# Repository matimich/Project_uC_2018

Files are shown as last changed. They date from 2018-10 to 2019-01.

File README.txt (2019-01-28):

# Project_uC_2018

The aim of the project is to design and construct position registration system based on STM32F411VET6 microcontroller.
The device will be using following modules:

-STM32F411EDISCOVERY board,
-GPS module,
-microSD card module,
-GSM module.

The project is prepared for a "Microcontrollers" subject.

Celem projektu jest zaprojektowanie i wykonanie rejestratora pozycji opartego na mikrokontrolerze STM32F411VET6.
Urządzenie będzie wykorzystywać następujące moduły:

- zestaw uruchomieniowy STM32F411EDISCOVERY,
- moduł GPS,
-czytnik kart pamięci microSD,
-moduł GSM.

Projekt jest przygotowywany na przedmiot mikrokontrolery.

W repozytorium można znaleźć następujące elementy:
-Definicje założeń:
Definicja_założeń.pdf

-Diagram Gantta(GanttProject):
Projekt_uC_rejestrator_Mateusz_Michalski.gan

-Przegląd_istniejących_rozwiązań:
Przegląd_istniejących_rozwiązań.pdf

-Specyfikacja_dobranych_elementów:
Kosztorys.pdf 	
Czytnik_kart_microSD.pdf
Moduł_GPS.pdf 		
Moduł_GSM.pdf 
Zasilanie.pdf
Zestaw_uruchomieniowy.pdf
Dodatkowe_elementy.pdf

-Schematy_projektu:
schematblokowy.pdf
Schemat_płytki_PCB.pdf
PCB.pdf
Schemat_Eagle.sch
PCB_Eagle.brd

-Kod_programu
kodu_programu-wstęp.pdf
Mikrokontrolery_projekt – plik zawierający cały kod programu

-Weryfikacja i wnioski
Weryfikacja i wnioski.pdf

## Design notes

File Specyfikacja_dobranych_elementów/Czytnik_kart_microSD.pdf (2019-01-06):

Moduł czytnika kart microSD Micro SD ARDUINO AVR

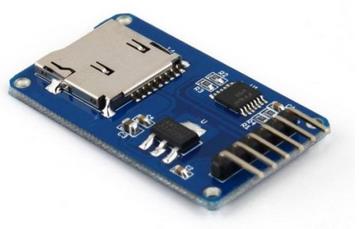
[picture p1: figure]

Czytnik karty pamięci micro SD.

Napięcie zasilania | 3,3 V
Napięcie pracy wyprowadzeń | 3,3 V
Komunikacja | SPI
Wbudowane gniazdo na kartę microSD | Jest
Wymiary płytki | 42 x 24 mm
Masa | 1,3 g

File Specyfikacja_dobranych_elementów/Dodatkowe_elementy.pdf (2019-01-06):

Obudowa ABB 1SL0846A00

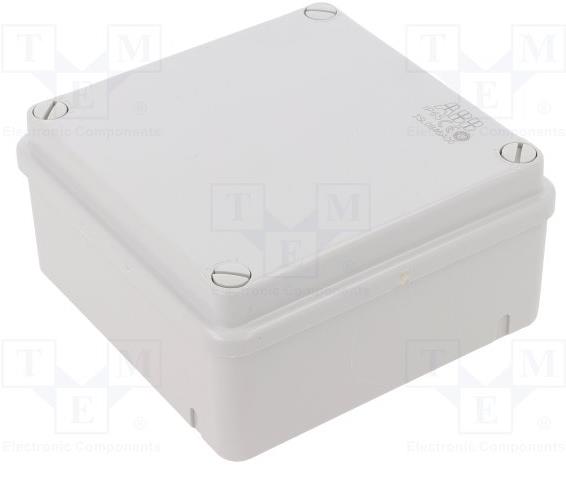
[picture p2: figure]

Producent | ABB
Typ obudowy | uniwersalna
Wymiar X | 100mm
Wymiar Y | 100mm
Wymiar Z | 50mm
Kolor obudowy | szary
Kolor pokrywy | szary
Montaż | natynkowy
Klasa szczelności | IP55
Masa brutto | 0.13 kg

Kondensator tantalowy VISHAY 293D225X9010A2TE3

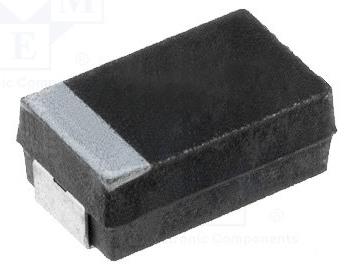
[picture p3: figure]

Producent | VISHAY
Typ kondensatora | tantalowy
Pojemność | 2.2µF
Napięcie pracy | 10V DC
Montaż | SMD
Obudowa | A
Obudowa - mm | 3216
Tolerancja | ±10%
Temperatura pracy | -55...125°C
Pojemność - nF | 2200nF

Kondensator ceramiczny KEMET C1206C104K5RACTU

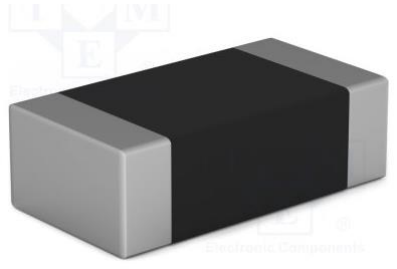
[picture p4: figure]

Producent | KEMET
Typ kondensatora | ceramiczny
Rodzaj kondensatora | MLCC
Pojemność | 100nF
Napięcie pracy | 50V DC
Dielektryk | X7R
Tolerancja | ±10%
Montaż | SMD
Obudowa - cal | 1206
Obudowa - mm | 3216
Temperatura pracy | -55...125°C
Pojemność - µF | 0.1µF

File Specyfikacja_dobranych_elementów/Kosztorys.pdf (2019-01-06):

### Kosztorys całkowity:

Nazwa: | Ilość: Cena(zł):
Moduł GSM GPRS SMS SIM800L + antena ARDUINO
SIMCOM
| 1 | 47,20
Moduł czytnika kart microSD Micro SD ARDUINO AVR | 1 | 5.90
Moduł GPS / GLONASS NEO-7M-C UART z anteną | 1 | 75
STM32F411E-Disco - Discovery - STM32F411EDISCOVERY | 1 | 94
Akumulator EverActive Silver Line R6 AA Ni-MH 2000mAh | 6 | 37.5
Stabilizator LDO 3,3V LF33CV - THT TO220 | 1 | 3.5
Stabilizator LDO 5V L4941BDT - SMD TO252 | 1 | 4.5
Koszyk na 6 baterii typu AA (R6) ze złączem DC 5,5/2,1mm | 1 | 6.5
Radiator RAD77 | 2 | 1.8
Gniazdo DC φ5.5 x 2.1 mm do druku - poziome | 1 | 0.5
Kondensator ceramiczny;MLCC;100nF | 2 | 0,5
Kondensator tantalowy;2,2uF;10VDC | 2 | 0,86
Dodatkowe komponenty | X | 5
Wykonanie płytki PCB | 1 | 30
Obudowa ABB 1SL0846A00 | 1 | 15
Suma | | 327.76

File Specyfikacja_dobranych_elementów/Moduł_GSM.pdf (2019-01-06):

Moduł GSM GPRS SMS SIM800L + antena ARDUINO SIMCOM

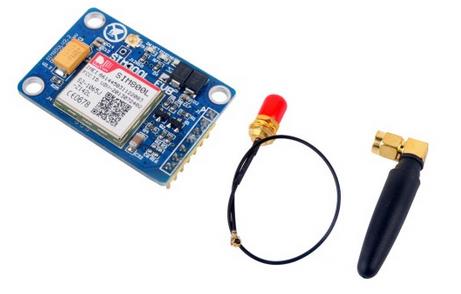
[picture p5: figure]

Napięcie pracy | 5 V
Natężenie prądu | 3 mA
Interfejs | UART (TTL)
Pasmo | GSM / GPRS: 850 / 900 / 1800 / 1900
| MHz
Slot na kartę | MicroSIM
Temperatura pracy | -40 ℃ do 85 ℃
Wymiary | 40x28mm
Waga | 34 g
Złącze antenowe | IPX

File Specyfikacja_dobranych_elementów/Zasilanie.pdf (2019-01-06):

Akumulator EverActive Silver Line R6 AA Ni-MH 2000mAh

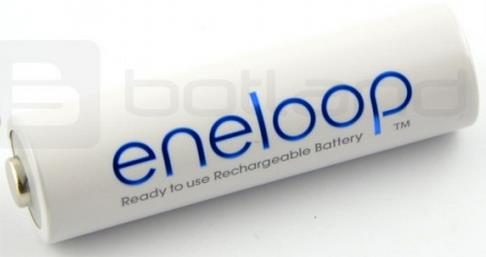
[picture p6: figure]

Napięcie wyjścia: | 1.2 V
Napięcie wyjściowe nominalne | 1.2 V
Pojemność mAh: | 2000 mAh
Obudowa | AA paluszek duży
Typ | Ni-Mh
Ilość | 6

Stabilizator LDO 3,3V LF33CV - THT TO220

Napięcie wejściowe max | 16 V
Napięcie wyjściowe | 3,3 V
Maksymalny prąd wyjściowy | 0,5 A

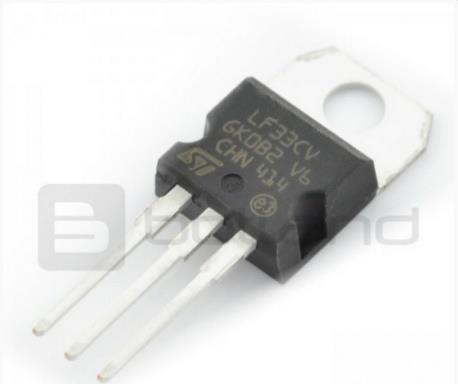
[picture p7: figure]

Dropout Voltage | Dla I = 0.2A Vd = 0.2V
| Dla I = 0.5A Vd = 0.4V
Obudowa | TO-220

Stabilizator LDO 5V L4941BDT - SMD TO252

Napięcie wejściowe max | 30 V
Napięcie wyjściowe | 5 V
Maksymalny prąd wyjściowy | 1 A

Dropout Voltage

Dla I = 0.5A Vd = 0.35V

Dla I = 0.5A Vd = 0.575V
Obudowa | TO-220

Koszyk na 6 baterii typu AA (R6) ze złączem DC 5,5/2,1mm

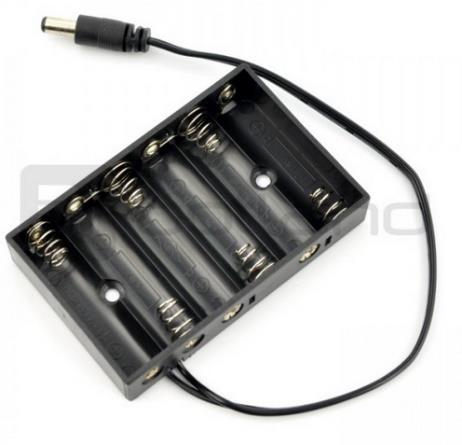
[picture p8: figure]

Obudowa | AA paluszek duży
Ilość | 6
Podłączenie | szeregowe

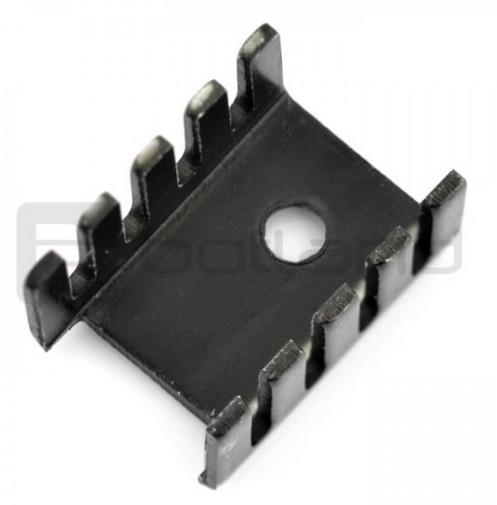
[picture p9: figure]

Radiator RAD77

Obudowa | TO220
Wymiary: | 19 x 13 x 9 mm

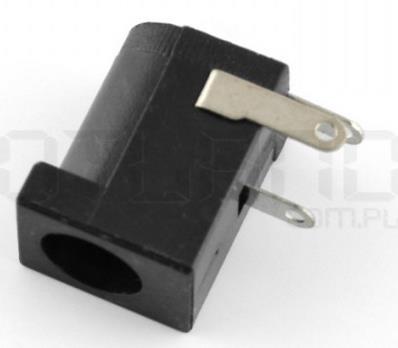
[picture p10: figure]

Gniazdo DC φ5.5 x 2.1 mm do druku – poziome

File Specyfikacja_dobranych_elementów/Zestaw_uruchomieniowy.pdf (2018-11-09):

Zestaw uruchomieniowy:

STM32F411E-Disco - Discovery - STM32F411EDISCOVERY

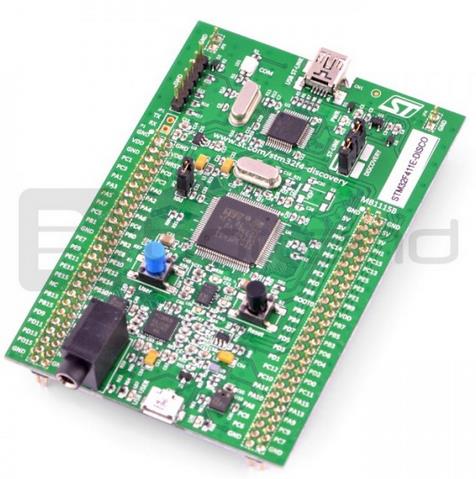
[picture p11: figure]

Mikrokontroler | STM32F411VET6
Rdzeń | Cortex M4F
Taktowanie | 100 MHz
Obudowa | LQFP100
Dodatkowo na płytce:
Akcelerometr 3 osiowy LSM303DLHC Żyroskop 3 osiowy L3GD20
Osiem diod LED

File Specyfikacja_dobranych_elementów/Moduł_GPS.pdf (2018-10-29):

Moduł GPS NEO-7M-C

Przedstawiony moduł pozwala nie tylko na odczytywanie współrzędnych geograficznych,

ale również daje informacje o innych parametrach takich jak: ilość dostępnych satelitów,

prędkość, wysokość lotu, czas utworzenia pomiaru, deklinacji magnetycznej itd.

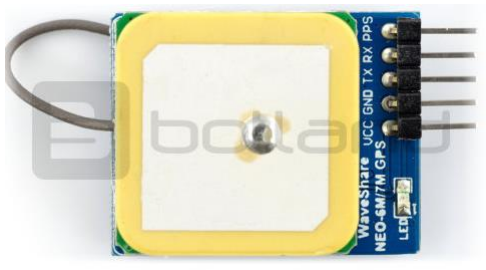
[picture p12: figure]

Rozpatrywany moduł NEO-7M-C.

napięcie pracy | 3.3 do 5 V
komunikacja poprzez interfejs | UART
częstotliwość odświeżania | 5 Hz
łączność satelitarna z systemami | GPS, GLONASS
dokładność pozycji | 2.5 m
odbieranie danych z modułu za pomocą standardu | NMEA

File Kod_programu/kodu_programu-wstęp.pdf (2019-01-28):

1) Przedstawienie wykorzystanego oprogramowania.

Kod programu został napisany w języku programowania C na mikrokontroler STM32F411VET6. Do obsłużenia peryferiów mikrokontrolera został wykorzystany program STM32CubeMX, natomiast dalsza edycja kodu została wykonana w środowisku programistycznym System Workbench for STM32. Podczas testowania urządzenia wykorzystany został program Realterm służący do komunikacji pomiędzy komputerem a mikrokontrolerem. Aby moduł GPS wysyłał odpowiednie informacje należało go najpierw poprawnie skonfigurować za pomocą aplikacji desktopowej u-center.

2) Ustawienia mikrokontrolera

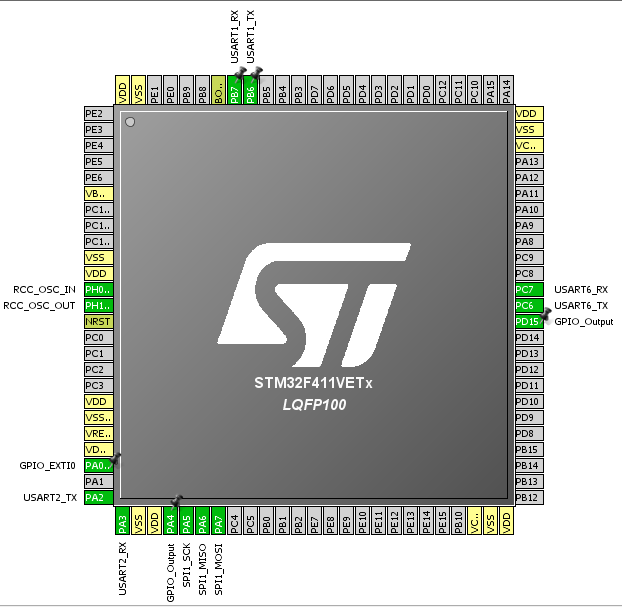
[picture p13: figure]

Zegar:
-prędkość zegara taktującego: 100 MHz + wykorzystanie kwarcu zewnętrznego, -przerwanie od timera ustawione na co 10 sekund.

Transmisja danych:
-USART1 – komunikacja modułu GPS z uC,
-USART2 – komunikacja modułu GSM z uC.
-USART6 – komunikacja mikrokontrolera z komputerem (do testów), -SPI1 – komunikacja modułu karty SD z uC.

Elementy dodatkowe:
-FATFS Mode and Configuration, “User-defined” – załączenie biblioteki FatFs.
3) Schemat działania programu

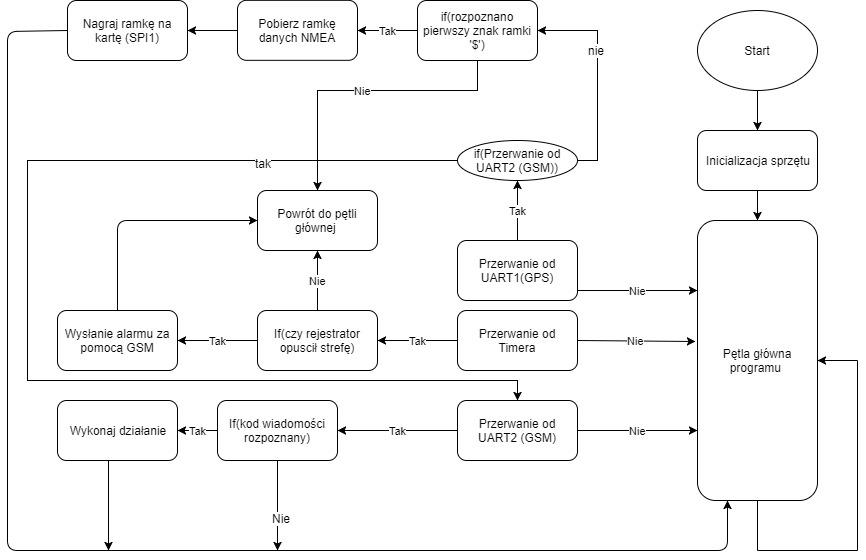
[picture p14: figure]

4) Wykorzystane biblioteki
Dodatkowo w projekcie zostały wykorzystane biblioteki::
- SPI_Card (plik „SPI_Card” w projekcie)
-pliki konfiguracyjne do obsługi karty microSD za pomocą transmisji SPI,
- EEPROM (plik „EEPROM” w projekcie)
-emulator pamięci flash, biblioteka wykorzystana w przyszłości do dalszego rozwoju projektu, dokładne wyjaśnienie zastosowania biblioteki w pliku „Weryfikacja i wnioski”.
5) Biblioteki własne
- GSM (plik „GSM” w projekcie)
-obsługa odbierania i otrzymywania wiadomości SMS,
-sprawdzanie numeru użytkownika (zabezpieczenie przed ingerencją osób trzecich,
- Zone (plik „Zone” w projekcie)
-analiza danych z modułu GPS, odczytanie współrzędnych geograficznych urządzenia i sprawdzenie czy urządzenie nie wyleciało poza ograniczoną strefę,
-utworzenie linku do google.com/maps z aktualna pozycją rejestratora.

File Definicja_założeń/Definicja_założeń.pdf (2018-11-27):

Założenia działania urządzenia:

High Level Requirements:

HLR1 – koordynowanie działań urządzenia za pomocą mikrokontrolera,

HLR2 – urządzenie ma możliwość uzyskania informacji o swoim aktualnym położeniu,

HLR3 – urządzenie zapisuje informację o położeniu na nośniku trwałym,

HLR4 –możliwość nawiązania kontaktu z urządzeniem za pomocą modułu GSM,

HLR5 – możliwość wysyłania aktualnej pozycji z urządzenia do użytkownika,

HLR6 – możliwość wyzwolenia alarmu w przypadku opuszczenia strefy zdefiniowanej przez użytkownika,

HLR7 – możliwość informowaniu użytkownika o opuszczeniu stref za pomocą modułu GSM,

HLR8 – system odporny przed niepożądaną ingerencją osób trzecich,

HLR9 – możliwość ładowania baterii urządzenia napięciem sieciowym,

HLR10 - system wykonany z możliwe tanich elementów,

HLR11 – wymiary urządzenia nieprzekraczające 100x70x70mm,

HLR12 – urządzenie pracuje w temperaturach umiarkowanych,

Low Level Requirements:

LLR1 – wykorzystanie 32-bitowego μC opartego na architekturze ARM,

LLR2 – μC pobiera pozycje z modułu GPS/GLONASS,

LLR3 – moduł GPS/GLONASS przetwarza dane w postaci ramki danych NMEA,

LLR4 – możliwość zapisu danych na karcie microSD,

LLR5 – źródło zasilania: 6x akumulatorów 1.2V Ni-MH 2000mAh, połączonych szeregowo,

LLR6 – moduł GPS/GLONASS zasilany napięciem 3V z μC,

LLR7 – moduł GSM zasilany napięciem 5V,

LLR8 – moduł czytnika karty microSD zasilany napięciem 3V,

LLR9 –μC zasilany napięciem 3V,

Dodatkowe założenia powstałe w procesie projektowania:

LLR10 – układ posiada wyprowadzenie masy.

LLR11 – układ posiada wyprowadzenie UART do podglądu otrzymywanych danych z modułu GPS.

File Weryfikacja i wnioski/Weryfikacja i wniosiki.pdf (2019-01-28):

Prototyp urządzenia

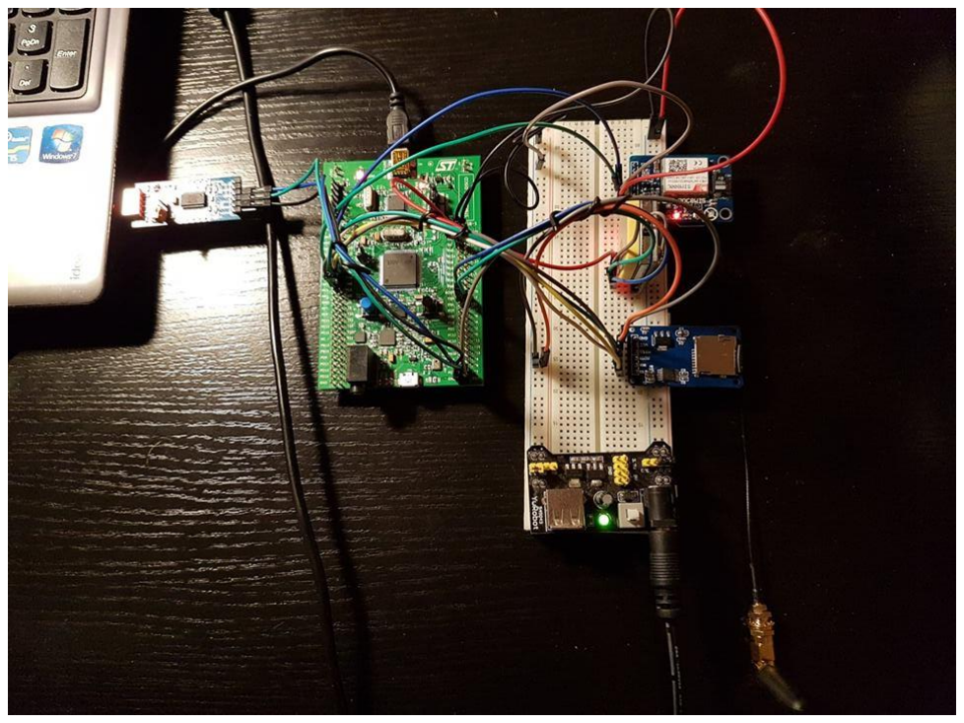
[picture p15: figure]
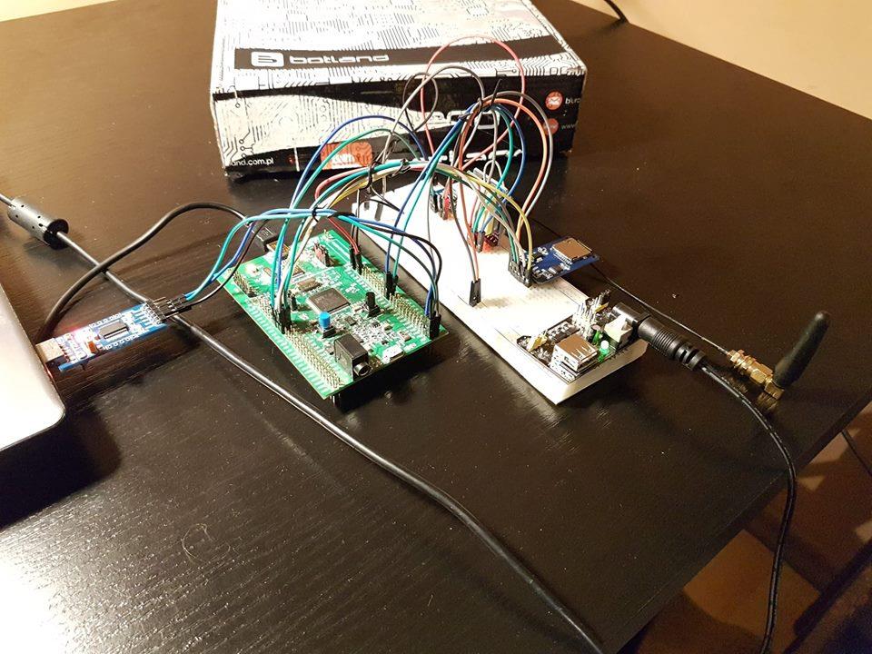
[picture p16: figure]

Weryfikacja i testy

a) HLR

Założenia
projektowe(HLR)
| Wynik: | Uzasadnienie wyniku:
HLR1 | + | Uzasadnienie 1
HLR2 | + | Test 1
HLR3 | - | Test 2
HLR4 | + | Test 3
HLR5 | + | Test 4
HLR6, HLR7 | + | Test 5
HLR8 | + | Test 6
HLR9 | + | Uzasadnienie 2
HLR10 | +/- | Uzasadnienie 3
HLR11 | +/- | Uzasadnienie 4
HLR12 | + | Uzasadnienie 5
- Uzasadnienie 1

HLR1 – koordynowanie działań urządzenia za pomocą mikrokontrolera,

Urządzenie wykorzystuje mikrokontroler do pracy. Wszystkie poniższe testy zostały wykonane z użyciem mikrokontrolera.

- Test 1

HLR2 – urządzenie ma możliwość uzyskania informacji o swoim aktualnym położeniu

Urządzenie zostało podpięte do komputera za pomocą adaptera UASRT-USB, następnie dane pobrane z moduły GPS zostały przesłane i wyświetlone na ekranie komputera za pomocą aplikacji Realterm. Wynikiem testu było pojawienie się ramki danych NMEA.

- Test 2

HLR3 – urządzenie zapisuje informację o położeniu na nośniku trwałym,

Pomimo długotrwałych prób i testów nie udało się nawiązać komunikacji pomiędzy modułem SD, a mikrokontrolerem za pomocą interfejsu SPI. W celu rozwiązania problemu, zostały przeprowadzone następujące podtesty:
-implementacji różnych bibliotek do obsługi modułu czytnika karty microSD za pomocą interfejsu SPI,
-sprawdzenie poprawności działania SPI w mikrokontrolerze,
- sprawdzenie modułu pod kątem potencjalnych zwarć,

Wynik: powyższe podtesty nie wykazały nieprawidłowości, błąd jest dalej poszukiwany.

- Test 3

HLR4 –możliwość nawiązania kontaktu z urządzeniem za pomocą modułu GSM,

Do obsługi modułu GSM zostały napisane funkcję, które umożliwiają komunikację pomiędzy mikrokontrolerem, a modułem GSM. W czasie testów, wiadomości tekstowe zostały poprawnie wysyłane jak i odebrane. Podobnie jak w przypadku Testu 1, dane wejściowe i wyjściowe z modułu były podglądane na komputerze co pozwoliło stwierdzić o poprawności działania urządzenia.

- Test 4

HLR5 – możliwość wysyłania aktualnej pozycji z urządzenia do użytkownika,

Sukcesem okazała się koordynacja modułu GPS z modułem GSM. Test polegał na wysłaniu do modułu odpowiedniej komendy i uzyskania odpowiedzi zwrotnej w postaci lokalizacji urządzenia. Wysyłając odpowiednią komendę urządzenie wysyła nam informację o aktualnej pozycji w dwóch możliwych formach:

-linku do „google.com/maps” z aktualna pozycją,

-ramkę danych NMEA

- Test 5

HLR6 – możliwość wyzwolenia alarmu w przypadku opuszczenia strefy zdefiniowanej przez użytkownika,

HLR7 – możliwość informowaniu użytkownika o opuszczeniu stref za pomocą modułu GSM,

Test polegał na ustawieniu granic strefy, tak aby nie obejmowała ona lokalizacji urządzenia. Program monitorując współrzędne geograficzne lokalizatora zauważył, iż znajduję się on poza dozwoloną strefą co spowodowało wysłanie wiadomość SMS z ostrzeżeniem.

- Test 6

HLR8 – system odporny przed niepożądaną ingerencją osób trzecich,

Za każdym razem gdy wiadomość jest odebrana, specjalna funkcja z biblioteki GSM porównuje otrzymany numer z numerem zapisanym w kodzie programu. W przypadku próby połączenia niezidentyfikowanego numeru, program nie wyśle odpowiedzi na zapytanie oraz odeśle wiadomość tekstową do zidentyfikowanego numeru użytkownika z informacją o próbie ingerencji.

Osoby trzecie nie mają możliwości uzyskania informacji o urządzeniu ponieważ aktualnie urządzenie ma zapisany numer użytkownika w kodzie programu (tj. urządzenie wysyła wiadomość tylko pod konkretny numer zdefiniowany w kodzie). Jest to jednocześnie wada urządzenia co zostanie uściślone w podsumowaniu i wnioskach.

- Uzasadnienie 2

HLR9 – możliwość ładowania baterii urządzenia napięciem sieciowym,

Urządzenie zostało zaprojektowane aby było zasilnie 6 akumulatorami Ni-MH, które w łatwy sposób mogą być ładowane przy użyciu ładowarek sieciowych.

- Uzasadnienie 3

HLR10 - system wykonany z możliwe tanich elementów,

Większość elementów zostało dobranych możliwie najekonomiczniej. Jednak cena dwóch wykorzystanych modułów znacząco odstaje od wartość pozostałych elementów, są to:

- Moduł GPS, cena: 75zł
- Zastaw uruchomieniowy, cena : 94zł

Elementy te mogły zostać dobrane w sposób bardziej ekonomiczny, jednak powodem ich wyboru było ich wcześniejsze posiadanie przez autora projektu.

- Uzasadnienie 4

HLR11 – wymiary urządzenia nieprzekraczające 100x70x70mm,

Wymiary zaprojektowanej płytki : 96x77, wymiary przekroczyły założenia projektowe

- Uzasadnienie 5

HLR12 – urządzenie pracuje w temperaturach umiarkowanych,

Dobrane komponenty pracują w zakresie temperatur umiarkowanych.

b) LLR
Założenia projektowe(LLR) | Wynik: | Uzasadnienie wyniku
LLR1 | + | Uzasadnienie 6
LLR2,LLR3 | + | Uzasadnienie 7
LLR4 | - | Uzasadnienie 8
LLR5,LL6,LLR7.LLR8,LLR9 | + | Uzasadnienie 9
LLR10/LLR11 | + | Uzasadnienie 10
- Uzasadnienie 6

LLR1 – wykorzystanie 32-bitowego μC opartego na architekturze ARM,

Urządzenie pracuje na 32-bitowym mikrokontrolerze opartym na architekturze ARM.

- Uzasadnienie 7

LLR2 – μC pobiera pozycje z modułu GPS/GLONASS,

LLR3 – moduł GPS/GLONASS przetwarza dane w postaci ramki danych NMEA,

Urządzenie wykorzystuje moduł GPS NEO-7M-C, który pobiera lokalizacje zarówno z systemu GPS jak i GLONASS w postaci ramki danych NMEA.

- Uzasadnienie 8

LLR4 – możliwość zapisu danych na karcie microSD,

Do urządzenia dobrano czytnik karty microSD jednak nie udało się poprawnie skonfigurować jego komunikacji z mikrokontrolerem. Problem ten został już opisany w podpunkcie „Test 2”.

- Uzasadnienie 9

LLR5 – źródło zasilania: 6x akumulatorów 1.2V Ni-MH 2000mAh, połączonych szeregowo,

LLR6 – moduł GPS/GLONASS zasilany napięciem 3V z μC,

LLR7 – moduł GSM zasilany napięciem 5V,

LLR8 – moduł czytnika karty microSD zasilany napięciem 3V,

LLR9 –μC zasilany napięciem 3V,

Wszystkie zasilania modułów jak i całego układu zostały dobrane w taki sposób aby spełnia postawione założenia projektowe.

- Uzasadnienie 10

LLR10 – układ posiada wyprowadzenie masy.

LLR11 – układ posiada wyprowadzenie UART do podglądu otrzymywanych danych z modułu GPS.

W projekcie płytki PCB zostały uwzględnione powyższe założenia, w przypadku wyprowadzenia UART, zostało ono również wykorzystane podczas powyższych testów.

Podsumowanie i wnioski

Praca na lokalizatorem zatrzymała się na etapie uzyskania urządzenia prototypowego. W czasie pracy na projektem udało się dobrać odpowiednie komponenty, zaprojektować płytkę PCB urządzenia oraz napisano kod programu do jego podstawowej koordynacji. Ponieważ prace na kodem były cały czas w fazie jego modyfikacji, wstrzymano się z trawieniem płytki PCB, gdyż w czasie poprawy kodu notorycznie występowały zmiany wyprowadzeń na poszczególnych pinach mikrokontrolera. Udało się nawiązać komunikacje procesora z modułem GPS oraz GSM. Mikrokontroler płynnie pobiera dane z modułu GPS, przetwarza ramki danych NMEA, reaguje na zmianę lokalizacji urządzenia oraz odpowiada na polecenia zadane przez użytkownika za pomocą komend wysłanych wiadomością SMS. Dużą wadą i jednocześnie porażką na etapie projektowym jest brak możliwości nagrywania danych na czytnik kart microSD za pomocą modułu SPI. Przeprowadzono wiele testów i badań mających na celu rozwiązanie problemu, problem ten będzie rozwiązywany w przyszłych wersjach projektu. Sam projekt posiada wiele elementów, które można rozwinąć lub poprawić w przyszłych wersjach. Jednym z nich jest brak możliwości konfiguracji urządzenia (punktów strefy monitorowanej oraz numeru użytkownika) z poziomu telefonu użytkownika. Aby to było możliwe dane wpisane przez użytkownika musiałyby być zapisywane w trwałej pamięci urządzenia. Potrzebne są do tego odpowiednie funkcję oferujące możliwość zapisu do pamięci FLASH. W celu przyszłego rozwiązania tego problemu zostały już poczynione pierwsze kroki. W kodzie programu z sukcesem została skonfigurowana biblioteka emulatora pamięć EEPROM, która w przyszłości posłuży do zapisu ustawień użytkownika. Warto również rozważyć wykorzystanie tańszych i mniejszych elementów do budowy kolejnych prototypów urządzenia, tj. rezygnacja z zestawu uruchomieniowego Discovery oraz drogiego modułu GPS NEO-7M-C.

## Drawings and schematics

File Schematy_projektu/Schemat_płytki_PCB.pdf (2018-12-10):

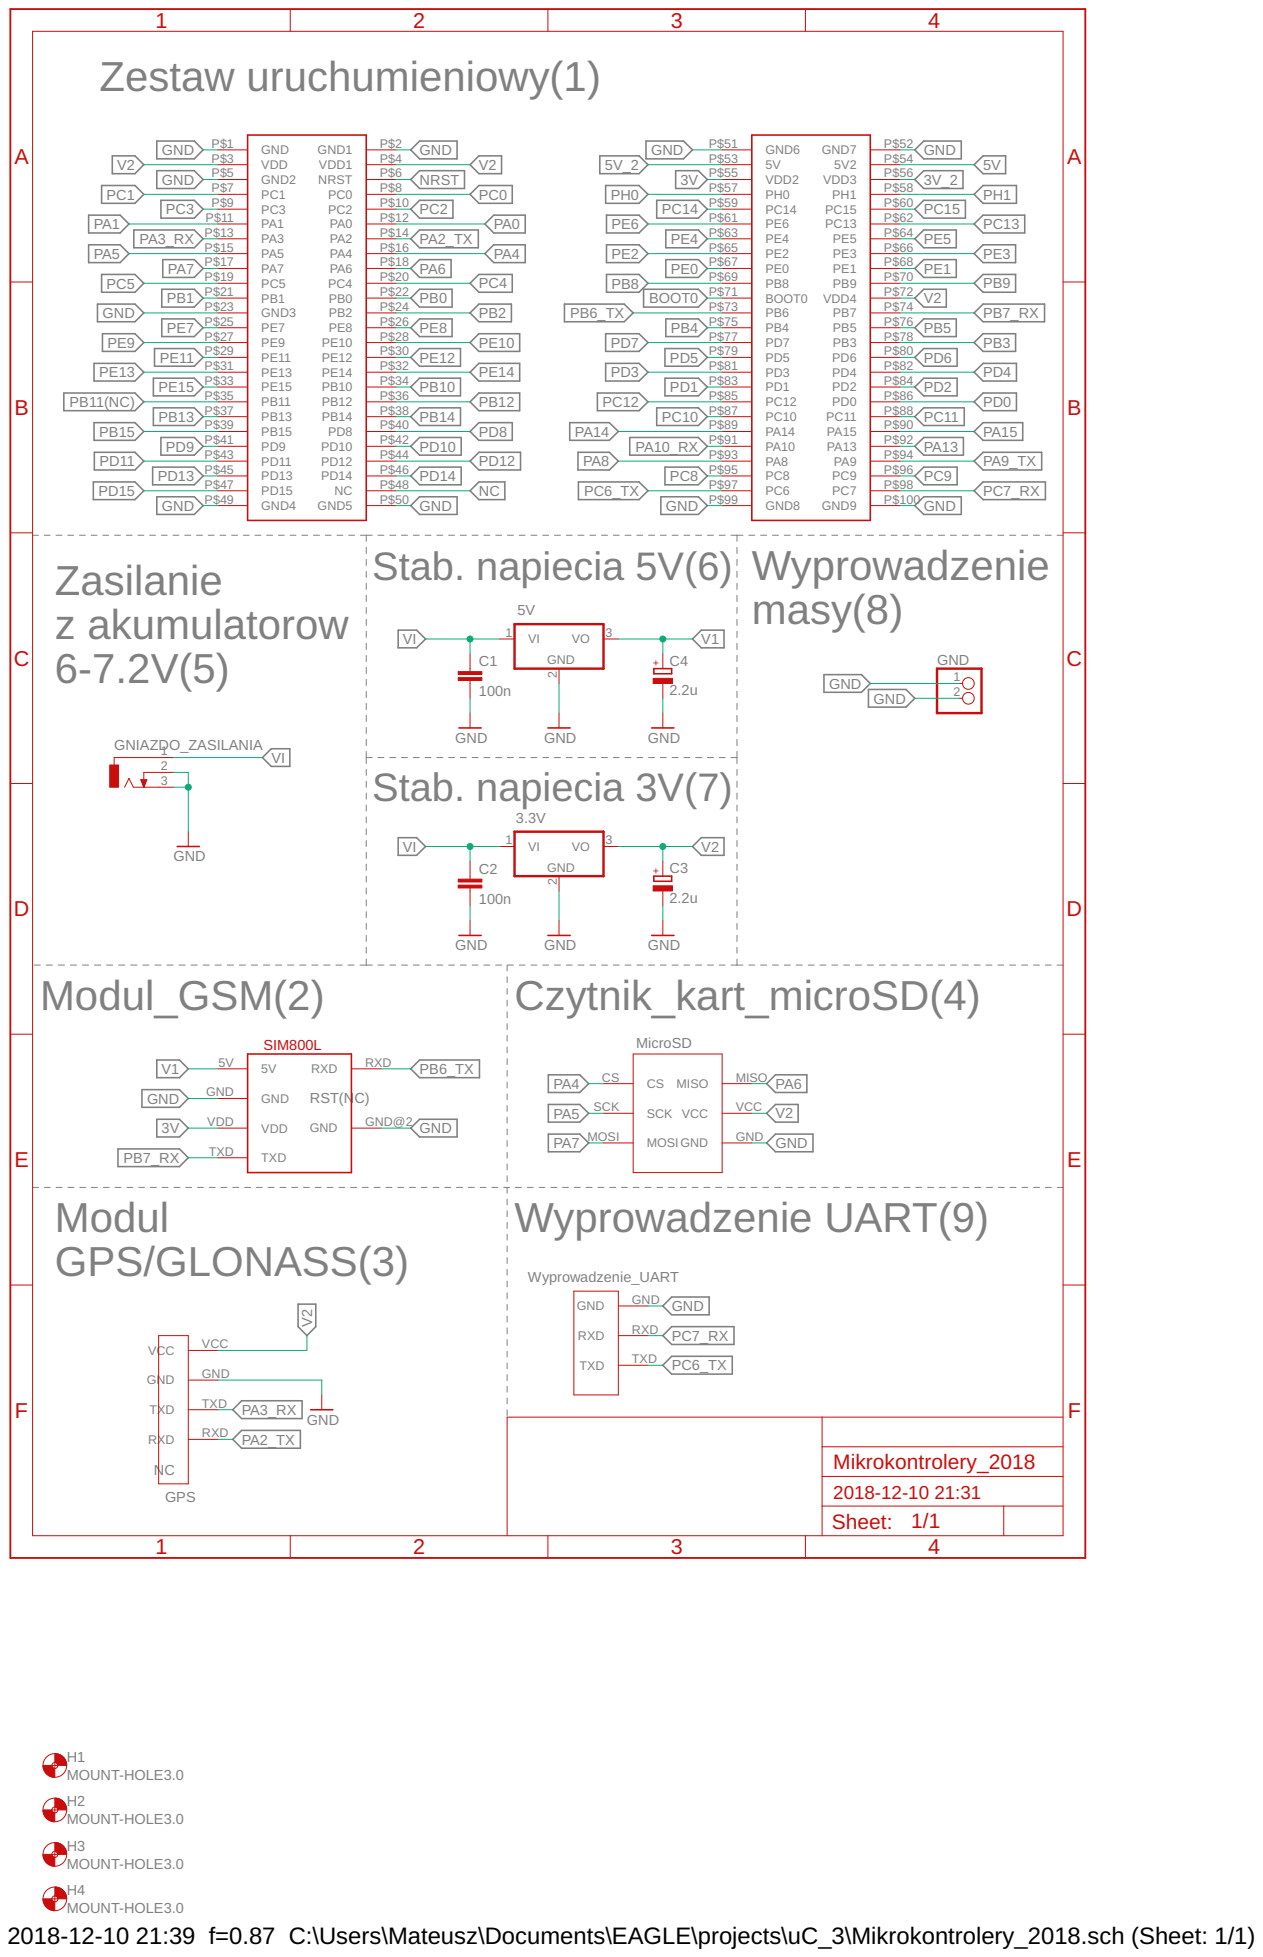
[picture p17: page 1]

MOUNT-HOLE3.0 MOUNT-HOLE3.0

2018-12-10 21:39 f=0.87 C:\Users\Mateusz\Documents\EAGLE\projects\uC_3\Mikrokontrolery_2018.sch (Sheet: 1/1)

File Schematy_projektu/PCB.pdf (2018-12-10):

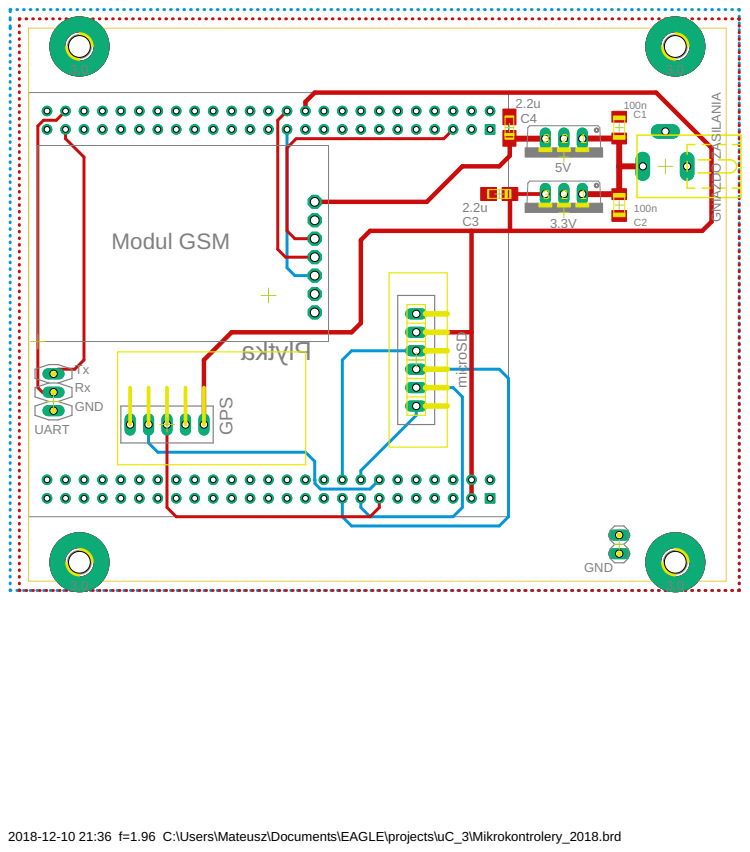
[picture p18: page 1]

2018-12-10 21:36 f=1.96 C:\Users\Mateusz\Documents\EAGLE\projects\uC_3\Mikrokontrolery_2018.brd

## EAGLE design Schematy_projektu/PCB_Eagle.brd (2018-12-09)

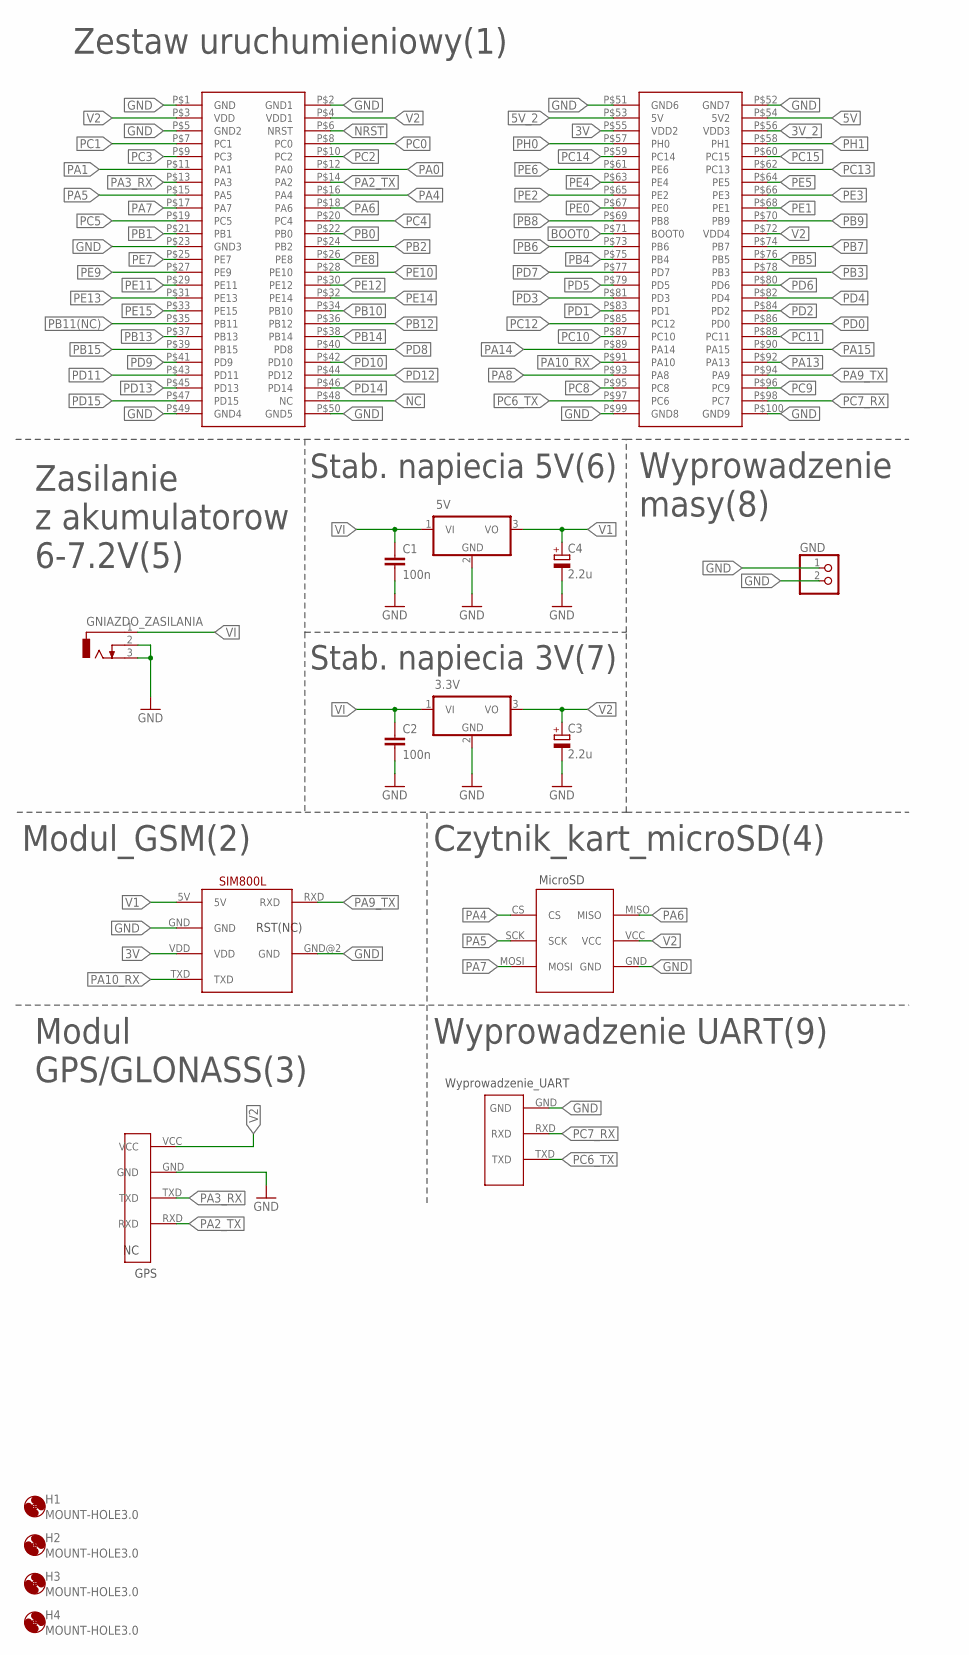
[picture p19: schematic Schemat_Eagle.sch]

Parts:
3.3V, 5V: 7805TV; TO220V
C1, C2: 100n; C1206K
C3, C4: 2.2u; A/3216-18W
GND: PINHD-1X2; 1X02
GNIAZDO_ZASILANIA: WEJSCIE_VCC; DCJ0202
H1, H2, H3, H4: MOUNT-HOLE3.0; 3,0
U$1: MODUL_GPS
U$3: MODUL_GSM
U$4: STM32F4-DISCOVERY
U$5: WYPROWADZENIE_UART
U$6: MICROSD

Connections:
3V: U$3.VDD, U$4.P$55 (VDD2)
3V_2: U$4.P$56 (VDD3)
5V: U$4.P$54 (5V2)
5V_2: U$4.P$53 (5V)
BOOT0: U$4.P$71 (BOOT0)
GND: 3.3V.2 (GND), 5V.2 (GND), C1.2, C2.2, C3.-, C4.-, GND.1, GND.2, GNIAZDO_ZASILANIA.2, GNIAZDO_ZASILANIA.3, U$1.GND, U$3.GND, U$3.GND@2 (GND), U$4.P$1 (GND), U$4.P$2 (GND1), U$4.P$5 (GND2), U$4.P$23 (GND3), U$4.P$49 (GND4), U$4.P$50 (GND5), U$4.P$51 (GND6), U$4.P$52 (GND7), U$4.P$99 (GND8), U$4.P$100 (GND9), U$5.GND, U$6.GND
NC: U$4.P$48 (NC)
NRST: U$4.P$6 (NRST)
PA0: U$4.P$12 (PA0)
PA1: U$4.P$11 (PA1)
PA2_TX: U$1.RXD, U$4.P$14 (PA2)
PA3_RX: U$1.TXD, U$4.P$13 (PA3)
PA4: U$4.P$16 (PA4), U$6.CS
PA5: U$4.P$15 (PA5), U$6.SCK
PA6: U$4.P$18 (PA6), U$6.MISO
PA7: U$4.P$17 (PA7), U$6.MOSI
PA8: U$4.P$93 (PA8)
PA9_TX: U$3.RXD, U$4.P$94 (PA9)
PA10_RX: U$3.TXD, U$4.P$91 (PA10)
PA13: U$4.P$92 (PA13)
PA14: U$4.P$89 (PA14)
PA15: U$4.P$90 (PA15)
PB0: U$4.P$22 (PB0)
PB1: U$4.P$21 (PB1)
PB2: U$4.P$24 (PB2)
PB3: U$4.P$78 (PB3)
PB4: U$4.P$75 (PB4)
PB5: U$4.P$76 (PB5)
PB6: U$4.P$73 (PB6)
PB7: U$4.P$74 (PB7)
PB8: U$4.P$69 (PB8)
PB9: U$4.P$70 (PB9)
PB10: U$4.P$34 (PB10)
PB11(NC): U$4.P$35 (PB11)
PB12: U$4.P$36 (PB12)
PB13: U$4.P$37 (PB13)
PB14: U$4.P$38 (PB14)
PB15: U$4.P$39 (PB15)
PC0: U$4.P$8 (PC0)
PC1: U$4.P$7 (PC1)
PC2: U$4.P$10 (PC2)
PC3: U$4.P$9 (PC3)
PC4: U$4.P$20 (PC4)
PC5: U$4.P$19 (PC5)
PC6_TX: U$4.P$97 (PC6), U$5.TXD
PC7_RX: U$4.P$98 (PC7), U$5.RXD
PC8: U$4.P$95 (PC8)
PC9: U$4.P$96 (PC9)
PC10: U$4.P$87 (PC10)
PC11: U$4.P$88 (PC11)
PC12: U$4.P$85 (PC12)
PC13: U$4.P$62 (PC13)
PC14: U$4.P$59 (PC14)
PC15: U$4.P$60 (PC15)
PD0: U$4.P$86 (PD0)
PD1: U$4.P$83 (PD1)
PD2: U$4.P$84 (PD2)
PD3: U$4.P$81 (PD3)
PD4: U$4.P$82 (PD4)
PD5: U$4.P$79 (PD5)
PD6: U$4.P$80 (PD6)
PD7: U$4.P$77 (PD7)
PD8: U$4.P$40 (PD8)
PD9: U$4.P$41 (PD9)
PD10: U$4.P$42 (PD10)
PD11: U$4.P$43 (PD11)
PD12: U$4.P$44 (PD12)
PD13: U$4.P$45 (PD13)
PD14: U$4.P$46 (PD14)
PD15: U$4.P$47 (PD15)
PE0: U$4.P$67 (PE0)
PE1: U$4.P$68 (PE1)
PE2: U$4.P$65 (PE2)
PE3: U$4.P$66 (PE3)
PE4: U$4.P$63 (PE4)
PE5: U$4.P$64 (PE5)
PE6: U$4.P$61 (PE6)
PE7: U$4.P$25 (PE7)
PE8: U$4.P$26 (PE8)
PE9: U$4.P$27 (PE9)
PE10: U$4.P$28 (PE10)
PE11: U$4.P$29 (PE11)
PE12: U$4.P$30 (PE12)
PE13: U$4.P$31 (PE13)
PE14: U$4.P$32 (PE14)
PE15: U$4.P$33 (PE15)
PH0: U$4.P$57 (PH0)
PH1: U$4.P$58 (PH1)
V1: 5V.3 (VO), C4.+, U$3.5V
V2: 3.3V.3 (VO), C3.+, U$1.VCC, U$4.P$3 (VDD), U$4.P$4 (VDD1), U$4.P$72 (VDD4), U$6.VCC
VI: 3.3V.1 (VI), 5V.1 (VI), C1.1, C2.1, GNIAZDO_ZASILANIA.1

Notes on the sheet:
Zestaw uruchumieniowy(1)
Zasilanie z akumulatorow 6-7.2V(5)
Modul GPS/GLONASS(3)
Modul_GSM(2)
Czytnik_kart_microSD(4)
Wyprowadzenie UART(9)
Wyprowadzenie masy(8)
Stab. napiecia 5V(6)
Stab. napiecia 3V(7)

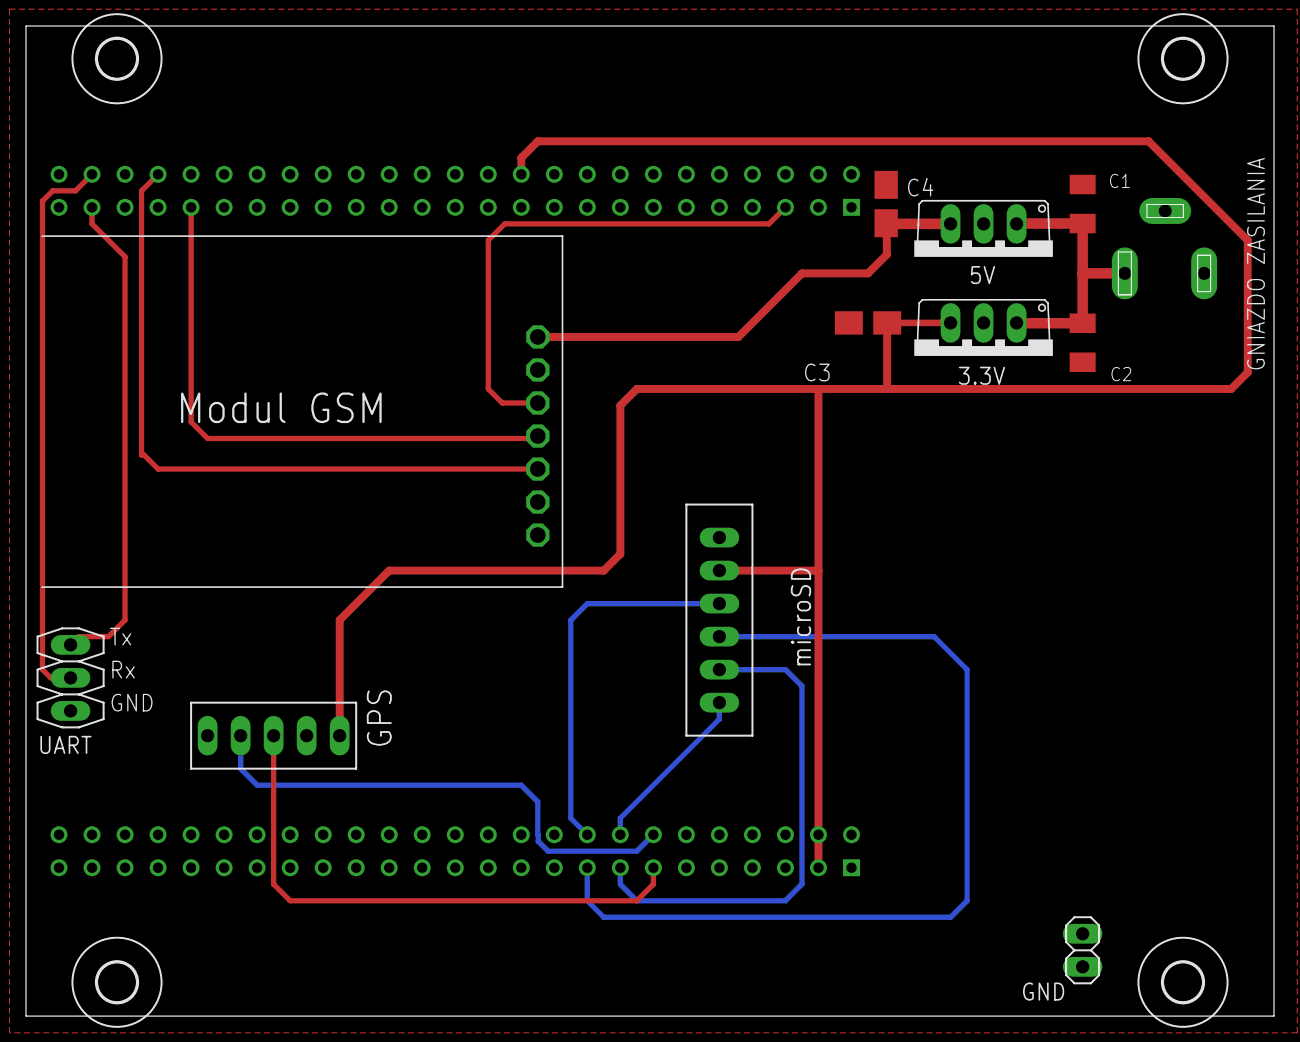
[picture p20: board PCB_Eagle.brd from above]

Board: 2 copper layers, 96.0 x 76.2 mm, 17 parts (1 on the bottom side), 15 nets.

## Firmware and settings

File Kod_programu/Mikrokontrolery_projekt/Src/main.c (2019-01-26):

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

/* Includes ------------------------------------------------------------------*/
#include "main.h"
#include "fatfs.h"

/* USER CODE BEGIN Includes */
#include <stdlib.h>
#include "zone.h"
#include <string.h>
#include "stm32f4xx_hal_flash.h"
#include "../SW4STM32/UART_GPS/EEPROM/eeprom.h"
#include "GSM.h"
/* USER CODE END Includes */

SPI_HandleTypeDef hspi1;
TIM_HandleTypeDef htim10;

UART_HandleTypeDef huart1;
UART_HandleTypeDef huart2;
UART_HandleTypeDef huart6;

/* USER CODE BEGIN PV */
uint8_t GPS_Rec[68];
uint8_t *GPS_Rec_2;
uint8_t GPS_Check;

FATFS FatFs;
FIL fil;
FRESULT fresult;

/*
// Zmienne biblioteki "EEPROM"
uint16_t VirtAddVarTab[NB_OF_VAR] = {0x5555, 0x6666, 0x7777};
uint16_t VarDataTab[NB_OF_VAR] = {0, 0, 0};
uint16_t VarValue,VarDataTmp = 77;
*/

/* parametry strefy */
int Szer_Gorna_Granica =  510000000; // 5100.00000,N
int Szer_Dolna_Granica = -490000000; // 4900.00000,S
int Dl_prawo_Granica = 215911430; // 02159.11430,E
int Dl_lewo_Granica = -205911430; // 02059.11430,W



/* USER CODE END PV */

void SystemClock_Config(void);
static void MX_GPIO_Init(void);
static void MX_USART6_UART_Init(void);
static void MX_USART1_UART_Init(void);
static void MX_TIM10_Init(void);
static void MX_SPI1_Init(void);
static void MX_USART2_UART_Init(void);
/* USER CODE BEGIN PFP */





void gsm(void)	// funkcja przetwazajaca polecenia od GSM
{
	if (GSM_Buff[1] == '1')	// #1 - wyslij aktualna pozycje
	{
		if ((char) GPS_Rec_2[17] == 'V' || (char) GPS_Rec_2[18] == 'V' || (char) GPS_Rec_2[9] == 'V')
		{
			GSM_send(NUMER,"Blad,gps nie odbiera sygnalu.\n\r");
		}
		else
		{
			char* source = (char*) malloc(85 * sizeof(uint8_t)); //dlugosc ramki stala, sprawdzone
			send_google((char*) GPS_Rec_2, source); //wlasna funkcja tworzaca link do google maps
			GSM_send(NUMER,source);
		}
	}

	else if (GSM_Buff[1] == '2') //#2 -ramka NMEA
	{
		GSM_send(NUMER,(char*)GPS_Rec_2);
	}

	else if (GSM_Buff[1] == '3') //#3 - RESET rejestratora
	{
		NVIC_SystemReset();
	}
	else if (GSM_Buff[1] == '4') //#4 - TEST
	{
		GSM_send(NUMER,"\n\r<GPS_Check>\n\r");
	}
	/*			/////Do rozwiniecia w przyszlosci
	else if (GSM_Buff[1] == '5') //#5 ustaw gorna szerokosc geograficzna za ktora rejestrator nie moze wyjsc
	{
		Szer_Gorna_Granica = 510000000;
		ustaw_punkt_GS(&Szer_Gorna_Granica);
	}

	else if (GSM_Buff[1] == '6') //#6 -ustaw dolna szerokosc geograficzna za ktora rejestrator nie moze wyjsc
	{
		VarValue = 16;
	    if((EE_WriteVariable(VirtAddVarTab[0],  VarValue)) != HAL_OK)
	    {
	    	//ustaw_punkt_A(&Szer_Gorna_Granica);
	    }
	}

	else if (GSM_Buff[1] == '7') //#7 -ustaw lewa granice dlugosci geograficznej za ktora rejestrator nie moze wyjsc
	{
	    if(EE_ReadVariable(VirtAddVarTab[0], &VarDataTmp) != HAL_OK)
	    {
	    	char* information = "blad odczytu\r\n";
	    	int length = sprintf(information,"blad odczytu\r\n");
	    	HAL_UART_Transmit(&huart6, (uint8_t*) information,(uint16_t) length,10);
	    }
	}
	else if (GSM_Buff[1] == '8') //#8 -ustaw prawa granice dlugosci geograficznej za ktora rejestrator nie moze wyjsc
	{
		//ustaw_punkt_A(&Szer_Gorna_Granica);
	}
	*/
}

void HAL_UART_RxCpltCallback(UART_HandleTypeDef *huart)
{
	if (GSM_Buff[0] != '#') // pobieranie ramki GPS wylaczone gdy nadawany jest GSM
	{
		if (GPS_Check == 10)	// wykrycie poczatku ramki NMEA, 10 == '$'
		{
			HAL_UART_Receive_IT(&huart1, GPS_Rec, 68);//odbierz cala ramke NMEA
			GPS_Rec_2 = GPS_Rec;	//przypisanie ramki do drugiego stringa

			f_lseek(&fil,f_size(&fil)); //przejscie na koniec pliku
			f_puts(GPS_Rec_2,&fil);	//zapis ramki na karte
			f_sync(&fil);		//"Flush cached data"

			GPS_Check = '0';	//wyczyszczenie znaku
			HAL_UART_Receive_IT(&huart1, &GPS_Check, 1);	//sprawdzaj ponowine
		}
		else
		{
			HAL_UART_Receive_IT(&huart1, &GPS_Check, 1);// szukaj znaku poczatku ramki
		}
	}


	if(huart->Instance == USART2)	//przerwanie od modulu GSM
	{
			if(GSM_Rx == '+')	//poczatek komunikatu od modulu GSM
			{
				if(GSM_rec_check() == 1)
				{
					save_mess(GSM_Buff);
					if (GSM_Buff[0] == '#')	//znak oznaczajacy detekcje polecenia od GSM
					{
						//HAL_GPIO_TogglePin(GPIOD, GPIO_PIN_15);
						gsm();
						GSM_Buff[0] = '0';	//wyczyszczenie komendy od GSM
						HAL_UART_Receive_IT(&huart2, &GSM_Rx, 1); 	// sprawdznie kolejnego znaku
					}
					else
					{
						HAL_UART_Receive_IT(&huart2, &GSM_Rx, 1); //czekaj na komunikat od GSM
					}
				}
				else
				{
					HAL_UART_Receive_IT(&huart2, &GSM_Rx, 1);
				}
			}
			else
			{
				HAL_UART_Receive_IT(&huart2, &GSM_Rx, 1);
			}
		}
}

void HAL_TIM_PeriodElapsedCallback(TIM_HandleTypeDef *htim)
{
	if(htim->Instance == TIM10)	//wykrycie timera zliczajecego co 10 sec
	{
		if(StrefaSzerokosc((char*)GPS_Rec_2,Szer_Gorna_Granica,Szer_Dolna_Granica) == 0
		||DlugoscSzerokosc((char*)GPS_Rec_2,Dl_prawo_Granica,Dl_lewo_Granica)== 0)	// sprawdzenie naruszenia strefy
		{
			GSM_send(NUMER,"\n\rLOKALIZATOR OPUSCIL WYZNACZONA STREFE!\n\r");
		}
	}
}

/* USER CODE END PFP */

/**
  * @brief  The application entry point.
  * @retval int
  */
int main(void)
{
  /* USER CODE BEGIN 1 */
	GPS_Rec_2 = (uint8_t*) malloc(68 * sizeof(uint8_t)); /* przyporzadkowanie pamieci dla stringa
	 przechowujacego ramke NMEA
	 */
  /* USER CODE END 1 */

  /* MCU Configuration--------------------------------------------------------*/

  /* Reset of all peripherals, Initializes the Flash interface and the Systick. */
  HAL_Init();

  /* Configure the system clock */
  SystemClock_Config();

  /* Initialize all configured peripherals */
  MX_GPIO_Init();
  MX_USART6_UART_Init();
  MX_USART1_UART_Init();
  MX_TIM10_Init();
  MX_SPI1_Init();
  MX_USART2_UART_Init();
  MX_FATFS_Init();
  /* USER CODE BEGIN 2 */

  HAL_UART_Receive_IT(&huart1, &GPS_Check, 1); //rozpoczecie odbierania danych  z GPS
  HAL_UART_Receive_IT(&huart2, &GSM_Rx, 1);   //rozpoczecie odbierania danych  z GSM
  HAL_TIM_Base_Start_IT(&htim10);			 //rozpoczecie pracy timera

  /*zapisanie poczatowych punktow strefy w pamieci flash */
  /*
  HAL_FLASH_Unlock();
  if( EE_Init() != EE_OK)	//inicializacja
  {
	   	  char* information = "blad inicializacji\r\n";
	   	  int length = sprintf(information,"blad inicializacji\r\n");
	   	  HAL_UART_Transmit(&huart6, (uint8_t*) information,(uint16_t) length,10);
  }
  {
    	EE_WriteVariable(VirtAddVarTab[0],  '+');	//+ lub -
    	EE_WriteVariable(VirtAddVarTab[1],  5);
    	EE_WriteVariable(VirtAddVarTab[2],  1);
    	EE_WriteVariable(VirtAddVarTab[3],  0);
    	EE_WriteVariable(VirtAddVarTab[4],  0);
    	EE_WriteVariable(VirtAddVarTab[5],  0);
    	EE_WriteVariable(VirtAddVarTab[6],  0);
    	EE_WriteVariable(VirtAddVarTab[7],  0);
    	EE_WriteVariable(VirtAddVarTab[8],  0);
    	EE_WriteVariable(VirtAddVarTab[9],  0);
    	EE_WriteVariable(VirtAddVarTab[10], 'X'); //znak separacji pomiedzy kolejnymi punktami
  }
*/
    GSM_rec_set();	//inicializacja modulu GSM
   //Inicializacja karty
	fresult = f_mount(&FatFs, "", 1);
	fresult = f_open(&fil, "file.txt", FA_CREATE_ALWAYS | FA_WRITE);


  /* USER CODE END 2 */

  /* Infinite loop */
  /* USER CODE BEGIN WHILE */




    while (1)
	{
    /* USER CODE END WHILE */

    /* USER CODE BEGIN 3 */

	}
  /* USER CODE END 3 */
}

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


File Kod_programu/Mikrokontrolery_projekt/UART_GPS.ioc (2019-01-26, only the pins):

Mcu.UserName=STM32F411VETx
PA0-WKUP.Signal=GPXTI0
PA2.Signal=USART2_TX
PA3.Signal=USART2_RX
PA4.Signal=SPI1_NSS
PA5.Signal=SPI1_SCK
PA6.Signal=SPI1_MISO
PA7.Signal=SPI1_MOSI
PB6.Signal=USART1_TX
PB7.Signal=USART1_RX
PC6.Signal=USART6_TX
PC7.Signal=USART6_RX
PD15.Signal=GPIO_Output

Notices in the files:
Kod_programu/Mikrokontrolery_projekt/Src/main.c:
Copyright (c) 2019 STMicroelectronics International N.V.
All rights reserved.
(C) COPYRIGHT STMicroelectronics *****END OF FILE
